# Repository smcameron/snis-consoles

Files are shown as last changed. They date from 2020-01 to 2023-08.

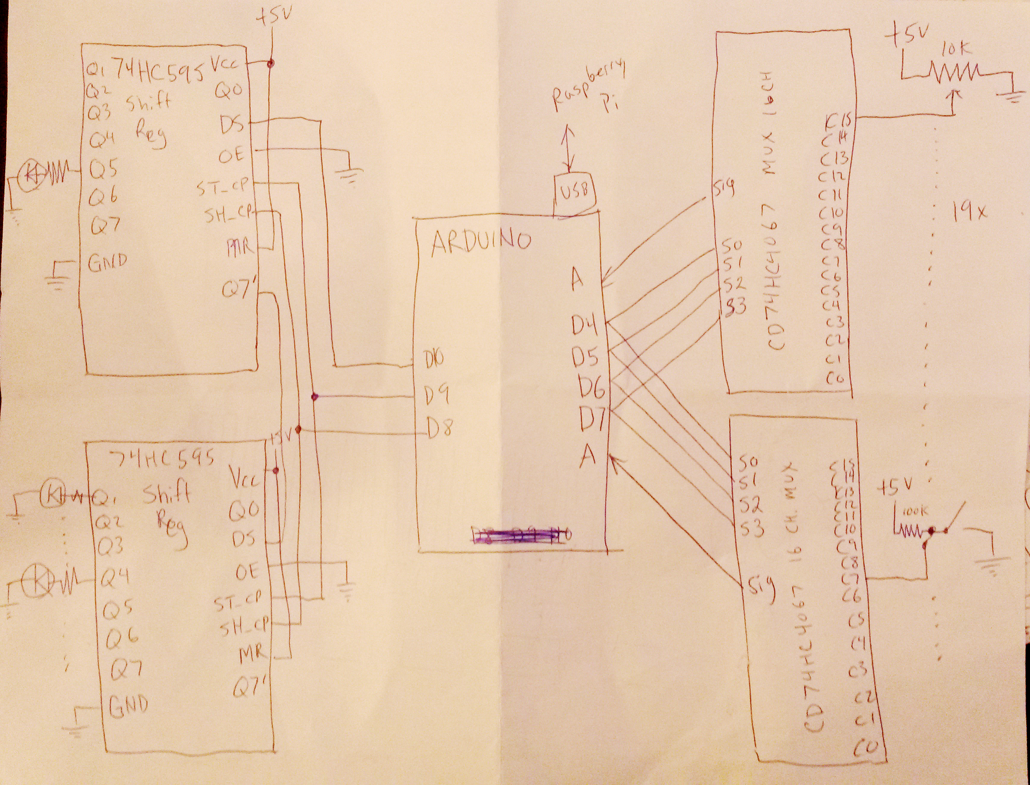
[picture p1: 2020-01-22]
notes/snis-console-circuit-sketch-2020-01-22.jpg

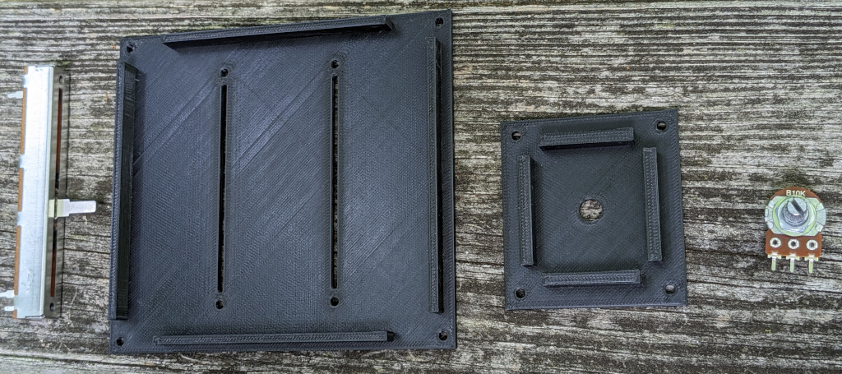
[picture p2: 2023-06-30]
notes/prototype-panel-inserts-back.jpg

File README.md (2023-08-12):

# snis-consoles

This repository contains some code and OpenSCAD designs for physical
consoles for the game <a href="https://spacenerdsinspace.com">Space Nerds in Space</a>.

It is still very much a work in progress.

The basic idea is to run snis_client on a Raspberry Pi 4B for some stations
(Navigation, Engineering, Science, Comms) and build a custom console for each
of these stations with buttons, toggle switches, potentiometer, faders, gauges,
etc.  An arduino (or maybe a Raspberry Pi pico) will marshal all these inputs
and control LEDs and so on, and be connected via USB to the Raspberry Pi 4B
running snis_client.

There are OpenSCAD designs for some 3D printable large illuminated push buttons
built around inexpensive tactile switches, some 3d printable panels to hold these
buttons and allow mounting into a "dashboard", some 3d printable panels for mounting
potentiometers and faders which can then mounted in a dashboard.

NOTE: for the gears and rack and pinion in the flight yoke model, you will
need to clone two additional repositories alongside this repository:

* git@github.com:smcameron/Rack-Pinion-openscadLib.git
* git@github.com:smcameron/meshing-gears-OpenSCAD.git

Here are some notes on my progress so far:

* [Notes](https://spacenerdsinspace.com/snis-consoles/notes.html)

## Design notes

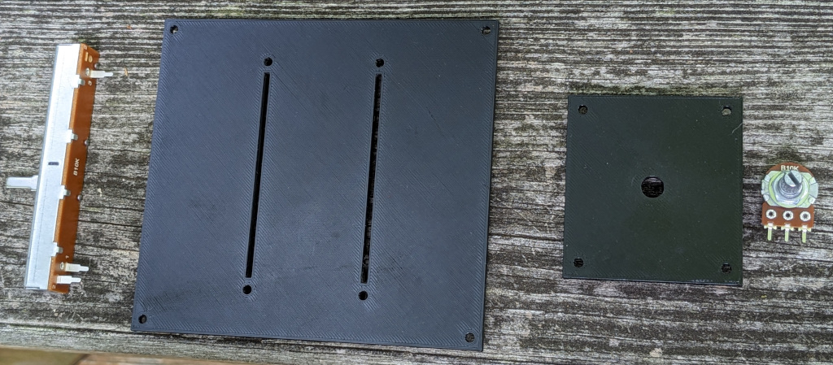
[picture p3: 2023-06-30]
notes/prototype-panel-inserts-front.jpg

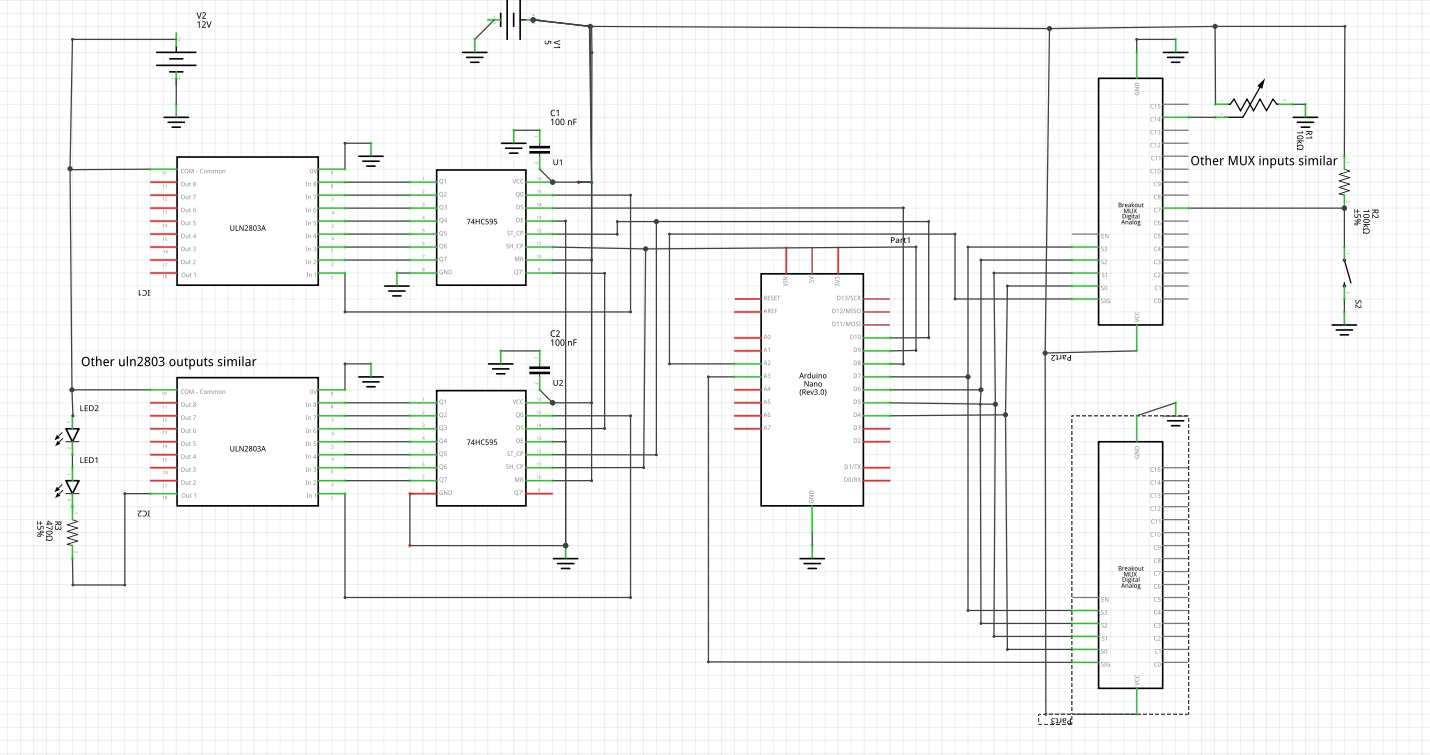
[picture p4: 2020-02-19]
notes/snis-console-circuit.png

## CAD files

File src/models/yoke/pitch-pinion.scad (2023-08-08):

/* using library from : git@github.com:smcameron/Rack-Pinion-openscadLib.git */

include <../../../../Rack-Pinion-openscadLib/RackPinionLibRedesign.scad>

// module pinion (cp, N, width, shaft_diameter, backlash=0){
// cp= circular pitch - for pinion pitch in mm/per as measured along the ptich radius (~1/2 way up tooth)
// N= number of teeth
// width= width of the gear
// shaft_diameter= diameter of hole for shaft
// backlash - I think this is just a bodge for making things fit when printed but I never tested it


/* 
 * 3mm per tooth
 * 65 teeth, = 147*4/3 mm rack length
 * 10mm wide
 * 5mm backing material
 *
 */
pinion(3, 65, 10, 6.0);

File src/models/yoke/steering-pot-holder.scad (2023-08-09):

pot_base_radius = (0.5 * 16.5);
pot_base_depth = 6;
pot_shaft_hole_radius = 3.7;

interior_width = 59;
exterior_width = 75;
plate_thickness = 3.0;

tolerance = 0.75;

$fn = 100;

module pot_tab_hole()
{
	translate(v = [13, 30, -3])
		translate(v = [0, 8.5, 0])
			cylinder(r1 = 1.8, r2 = 1.8, h = 10);
}

module base_plate()
{
	union() {
		translate(v = [-5, 0, 0])
			cube(size = [plate_thickness, interior_width - tolerance, 30]);
		translate(v = [plate_thickness, -8, 0])
			cube(size = [plate_thickness, 15, 30]);
		translate(v = [plate_thickness, interior_width - 8, 0])
			cube(size = [plate_thickness, 15, 30]);
		translate(v = [-2, 0, 0])
			cube(size = [8, 8, 30]);
		translate(v = [-2, 50.2, 0])
			cube(size = [8, 8, 30]);
	}
}

module pot_plate()
{
	difference() {
		translate(v = [-5, 15, 0])
			cube(size = [25, 30, 4]);
		translate(v = [13, 30, -2])
			cylinder(r1 = pot_shaft_hole_radius, r2 = pot_shaft_hole_radius, h = 20);
		pot_tab_hole();
		translate(v = [-5.1, 0, -0.1])
			cube(size = [plate_thickness + 0.1, 100, 2 * plate_thickness]);
	}
}

module gusset()
{
	scale(v = [1, 1, 2]) {
	rotate(v = [0, 0, 1], a = 90)
	difference() {
		cube(size = [4, 10, 10]);
		translate(v = [-0.5, 0, 0])
			rotate(v = [1, 0, 0], a = 45)
				cube(size = [5, 20, 20]);
	}
	}
}

module gussets()
{
	translate(v = [8, 15, 4])
			gusset();
	translate(v = [8, 41, 4])
			gusset();
}

module screw_hole()
{
	rotate(v = [0, 1, 0], a = 90)
		cylinder(r1 = 1.75, r2 = 1.75, h = 100);
}

union() {
union() {
	base_plate();
}

translate(v = [0, -1, 0]) {
	pot_plate();
	gussets();
	translate(v = [-5 + plate_thickness, 5, 0])
		cube(size = [plate_thickness, 15, 30]);
	translate(v = [-5 + plate_thickness, 40, 0])
		cube(size = [plate_thickness, 15, 30]);
}
}

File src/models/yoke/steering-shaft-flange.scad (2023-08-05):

shaft_radius = (0.5 * 22.5);
flange_length = 15;
flange_lip_height = 4;
large_radius = shaft_radius * 1.5;
small_radius = shaft_radius * 1.2;
$fn = 100;

difference() {
	union() {
		translate(v = [0, 0, 0.5 * flange_length]) {
			cylinder(h = flange_length, r1 = small_radius, r2 = small_radius, center = true);
		}
		translate(v = [0, 0, 0.5 * flange_lip_height])
			cylinder(h = flange_lip_height, r1 = large_radius, r2 = large_radius, center = true);
	}
	translate(v = [0, 0, 0.5 * flange_length])
		cylinder(h = flange_length * 2, r1 = shaft_radius, r2 = shaft_radius, center = true);
	translate(v = [-20, 0, 10])
		rotate(v = [0, 1, 0], a = 90)
			cylinder(h = 40, r1 = 2, r2 = 2);
}

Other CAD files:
src/models/yoke/steering-shaft-gear.scad
src/models/cantilever-snap.scad
src/models/case_siding.scad
src/models/face-plate.scad
src/models/fader-60mm-holes.scad
src/models/fader-insert-60mm-array.scad
src/models/gauge/gauge.scad
src/models/gauge/needle.scad
src/models/large-switch-array-holder.scad
src/models/large-switch.scad
src/models/lasercut-lenses.scad
src/models/lower-panel.scad
src/models/nav-2x2-large-switch-array-holder.scad
src/models/nav-2x2-switch-retaining-gasket.scad
src/models/nav-2x5-large-switch-array-holder.scad
src/models/nav-2x5-switch-retaining-gasket.scad
src/models/nav-5x1-large-switch-array-holder.scad
src/models/nav-5x1-switch-retaining-gasket.scad
src/models/nav-5x1-toggle-switch-insert.scad
src/models/nav-5x4-large-switch-array-holder.scad
src/models/nav-impulse-warp-fader-insert.scad
src/models/nav-zoom-pot-insert.scad
src/models/potentiometer-hole.scad
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

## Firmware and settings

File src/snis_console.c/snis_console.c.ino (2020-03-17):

/*
	Copyright (C) 2020 Stephen M. Cameron
	Author: Stephen M. Cameron

	This file is part of Spacenerds In Space.

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
	You should have received a copy of the GNU General Public License
	along with Spacenerds in Space; if not, write to the Free Software
	Foundation, Inc., 51 Franklin St, Fifth Floor, Boston, MA  02110-1301  USA
*/

/* Multiplexer selector pins */
static const int mux_select[4] = { 4, 5, 6, 7 };
static const int mux_input[2] = { A2, A3 };

/* Shift register control pins */
static const int sr_data = 8;
static const int sr_clock = 9;
static const int sr_latch = 10;

/* Changes below +/- 3 won't register... cuts down on spurious triggers
 * Might be able to tighten this up when no longer using the breadboard
 * when the real circuit is built. */
#define MUX_SIGNAL_THRESHOLD 3

static int current_input[32] = { 0 };
static int old_input[32] = { 0 };
static int indicator_led[16] = { 0 };



#define ENGINEERING 1

#ifdef ENGINEERING
#define CONSOLE_CHAR 'E'
#endif
#ifdef WEAPONS
#define CONSOLE_CHAR 'W'
#endif
#ifdef NAVIGATION
#define CONSOLE_CHAR 'N'
#endif
#ifdef COMMS
#define CONSOLE_CHAR 'C'
#endif
#ifdef SCIENCE
#define CONSOLE_CHAR 'S'
#endif
#ifdef DEMON
#define CONSOLE_CHAR 'D'
#endif

void setup()
{
	int i;

	Serial.begin(9600);

	/* Set up output pins for mux channel selection */
	for (i = 0; i < 4; i++)
		pinMode(mux_select[i], OUTPUT);
	pinMode(mux_input[0], INPUT);
	pinMode(mux_input[1], INPUT);
	pinMode(sr_data, OUTPUT);
	pinMode(sr_clock, OUTPUT);
	pinMode(sr_latch, OUTPUT);
	digitalWrite(sr_data, LOW);
	digitalWrite(sr_latch, LOW);
	digitalWrite(sr_clock, LOW);
}

void select_mux_channel(int channel)
{
	for (int i = 0; i < 4; i++)
		digitalWrite(mux_select[i], (channel >> i) & 0x01);
}

void read_mux_input(int current_input[])
{
	for (int i = 0; i < 16; i++) {
		select_mux_channel(i);
		current_input[i] = analogRead(mux_input[0]);
		current_input[i + 16] = analogRead(mux_input[1]);
	}
}

#ifndef TEST_SNIS_CONSOLE
#define printchar print
#define printint print
#define printintln println
#endif

void transmit_input(int datum, int value)
{
	Serial.printchar(CONSOLE_CHAR);
	Serial.printint(datum);
	Serial.printchar('=');
	Serial.printintln(value);
}

void transmit_changed_input(int current_input[], int old_input[])
{
	int i;

	for (i = 0; i < 32; i++) {
		if (abs(current_input[i] - old_input[i]) > MUX_SIGNAL_THRESHOLD) {
			transmit_input(i, current_input[i]);
			old_input[i] = current_input[i];
		}
	}
}

struct serial_input_data {
	int active_command;
#define NO_COMMAND 0
#define LED_STATUS_COMMAND 'L'
	int index;
	int hex_digit_count;
	uint8_t led_values[2];
	uint8_t *value_ptr;
} sid = { 0 };

void update_indicator_leds(void)
{
	int i;

	for (i = 0; i < 16; i++) { /* Shift out 16 bits of LED indicator data to turn on/off 16 indicator LEDs */
		digitalWrite(sr_clock, LOW);
		digitalWrite(sr_data, indicator_led[i] ? HIGH : LOW);
		digitalWrite(sr_clock, HIGH);
	}
	digitalWrite(sr_latch, HIGH); /* Latch the data so it appears on the outputs of the shift registers */
	digitalWrite(sr_latch, LOW);
}

void read_indicator_data_from_snis_client_and_update_leds(void)
{
	/* Sat Feb 22 15:15:14 EST 2020 -- this function is completely untested. */

	int i, inchar, value;
	uint16_t v;

	if (Serial.available() <= 0)
		return;

	/* Read a character... */
	inchar = Serial.read();
	if (inchar == -1) /* no data */
		return;

	switch (inchar) {
	/* LED status values, expect 2 more bytes to indicate status of 16 LEDs */
	case LED_STATUS_COMMAND:
		sid.value_ptr = &sid.led_values[0];
		sid.hex_digit_count = 4; /* 2 bytes with 2 hex digits each */
		sid.active_command = LED_STATUS_COMMAND;
		return;
	default:
		/* If no active command, or we already have the data for the active command
		 * ignore this character and continue.
		 */
		if (sid.active_command == 0 || sid.hex_digit_count <= 0)
			return;

		/* Convert value to integer */
		if (inchar >= '0' && inchar <= '9')
			value = inchar - '0';
		else if (inchar >= 'A' && inchar <= 'F')
			value = inchar - 'A' + 10;
		else
			value = -1;

		/* If we did not get a good value, ignore it. */
		if (value < 0)
			return;
		/* We got a good value, store it */
		if ((sid.hex_digit_count % 2) == 0)
			*sid.value_ptr = ((uint8_t) value << 4) & 0xf0; /* high nybble */
		else
			*sid.value_ptr |= (uint8_t) (value & 0x0f); /* low nybble */
		if (sid.hex_digit_count % 2)
			sid.value_ptr++;
		sid.hex_digit_count--;
		if (sid.hex_digit_count == 0)
			update_indicator_leds();
		break;
	}

	/* If we have still more data to read continue reading more.  */
	if (sid.hex_digit_count != 0)
		return;

	/* We have all the data for the active command, so process it. */
	switch (sid.active_command) {
	case LED_STATUS_COMMAND: /* Update the indicator LED status values with the data */
		sid.active_command = NO_COMMAND;
		memcpy(&v, sid.led_values, sizeof(v));
		for (i = 0; i < 16; i++)
			indicator_led[i] = v & (0x1 << i);
		return;
	default:
		/* Unknown command... */
		return;
	}
}

void loop() {

	read_mux_input(current_input);
	transmit_changed_input(current_input, old_input);
	read_indicator_data_from_snis_client_and_update_leds();
}

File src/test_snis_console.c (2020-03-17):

#include <stdio.h>
#include <stdlib.h>
#include <stdint.h>
#include <string.h>

#define A2 0
#define A3 1

#define INPUT 0
#define OUTPUT 1
#define HIGH 1
#define LOW 0

int analog_values[] = {
	0, 1, 2, 3, 4, 5, 6, 7, 8, 9, 10, 11, 12, 13, 14, 15, 16, 17, 18, 19, 20, 21, 22, 23, 24, 25, 26, 27, 28, 29, 30, 31,
};


int emu_mux_select_pin[] = { 4, 5, 6, 7, };
int emu_mux_select = 0;
int emu_mux_input[] = { A2, A3 };

/* Shift register control pins */
static const int emu_sr_data = 8;
static const int emu_sr_clock = 9;
static const int emu_sr_latch = 10;
static int sr_data_value = 0;
static int sr_clock_value = 0;
static int sr_latch_value = 0;
uint16_t shift_register = 0;
uint16_t shift_register_output = 0;

typedef void (*intfunc)(int x);
typedef int (*intvoidfunc)(void);

static int analogRead(int pin)
{
	printf("Analog read %d\n", pin);

	if (pin == emu_mux_input[0]) {
		printf("Reading mux input 0, emu_mux_select = %d, returning %d\n",
				emu_mux_select, analog_values[emu_mux_select]);
		return analog_values[emu_mux_select];
	} else if (pin == emu_mux_input[1]) {
		printf("Reading mux input 1, emu_mux_select = %d, returning %d\n",
				emu_mux_select, analog_values[emu_mux_select + 16]);
		return analog_values[emu_mux_select + 16];
	}  
	return 0;
}

static void digitalWrite(int pin, int value)
{
	int i;

	printf("digital write pin/value: %d/%d\n", pin, value);

	for (i = 0; i < 4; i++) {
		if (pin == emu_mux_select_pin[i]) {
			emu_mux_select = ((emu_mux_select & ~(0x01 << i)) | (value << i));
			return;
		}
	}

	if (pin == emu_sr_data) {
		sr_data_value = value & 0x01;
	} else if (pin == emu_sr_clock) {
		if (value == HIGH && sr_clock_value == LOW) {
			shift_register = (shift_register << 1) & 0xfffe;
			shift_register |= (sr_data_value & 0x01);
		}
		sr_clock_value = value;
	} else if (pin == emu_sr_latch) {
		if (value == HIGH && sr_latch_value == LOW) {
			shift_register_output = shift_register;
			printf("Latched shift register value: %04x\n", shift_register_output);
		}
		sr_latch_value = value;
	}
}

static void Serial_Begin(int x)
{
	printf("Serial.Begin(%d);\n", x);
}

static void Serial_printint(int x)
{
	printf("%d", x);
}

static void Serial_printintln(int x)
{
	printf("%d\n", x);
}

static void Serial_printchar(int x)
{
	printf("%c", x);
}

static int Serial_read(void)
{
	static int p = 0;
	const char *led_data = "LBEEF";
	int x;

	x = led_data[p];
	p = (p + 1) % 5;
	return x;
}

static int Serial_available(void)
{
	return 1;
}

static void pinMode(int a, int b)
{
	return;
}

struct serial {
	intfunc begin;
	intfunc printint;
	intfunc printintln;
	intfunc printchar;
	intvoidfunc read;
	intvoidfunc available;
} Serial = {
	Serial_Begin,
	Serial_printint,
	Serial_printintln,
	Serial_printchar,
	Serial_read,
	Serial_available,
};

#define TEST_SNIS_CONSOLE

#include "snis_console.c/snis_console.c.ino"

int main(int argc, char *argv[])
{
	printf("Test code for snis_console...\n");
	setup();
	do {
		loop();
	} while (1);
}

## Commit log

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2020-01-25 Refine change detection of multiplexer inputs and tighten up output
    There seems to be a little cross talk and settling time on the mux signal.
    Quite likely this is due to the breadboard though, once I get the real
    circuit built, might be able to tighten this up.
    [snis_console.c.ino]
2020-01-29 Differentiate between different stations in protocol.
    Previously messages from Arduino to host were of the form:
    #X=y\n
    Replace the '#' with a symbol to indicate which console, e.g.
    E=engineering/damage control
    N=Navigation
    W=Weapons
    C=Comms
    S=Science
    D=Demon
    [snis_console.c.ino]
2020-01-31 Copy current_data[i] to old_data[i] when it changes
    Previously we just memcpy'ed the entrie current_data[]
    to old_data[] whether it changed or not. However, this caused
    a bug that the data could very slowly change bit by bit and accumulate
    a large amount of change without ever registering as having changed. If
    we only copy the data when it changes, then small changes that accumulate
    to large changes will register.
    [snis_console.c.ino]
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2020-02-02 add 3d model for switch holder
    [switch.scad]
2020-02-02 Fix model to be a proper 2-manifold or whatever
    [switch.scad]
2020-02-03 Refine button pusher design
    [switch.scad]
2020-02-03 increase size of cavity to hold tactile switch
    [switch.scad]
2020-02-03 Refine rabbet on button pusher
    [switch.scad]
2020-02-03 Add a flange to the case for mounting in a panel
    [switch.scad]
2020-02-03 Inset the button cavity deeper into the floor of the button holder
    [switch.scad]
2020-02-03 Adjust LED hole position
    [switch.scad]
2020-02-04 Adjust button pusher contact point
    [switch.scad]
2020-02-04 Add friction arms to the button holder
    [switch.scad]
2020-02-06 More little adjustments -- at this point, the pieces fit together and actually work.
    [switch.scad]
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2020-02-19 Remove bypass caps from 4067 breakout board - it already has them built in
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2020-03-17 Fix bug in read_indicator_data_from_snis_client
    It was only reading 2 hex digits but needs to read 4 digits for 2 bytes
    [snis_console.c.ino]
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2021-08-28 Allow gangs of switches
    [switch.scad]
2022-08-17 Add fader60mm-holes.scad
    [fader-60mm-holes.scad]
2022-08-17 Add toggle-switch-hole.scad
    [toggle-switch-hole.scad]
2022-08-17 Add potentiometer-hole.scad
    [potentiometer-hole.scad]
2022-08-17 Add switch-hole.scad
    [switch-hole.scad]
2022-08-17 Add test-panel.scad
    [test-panel.scad]
2023-06-16 Add model for 3d printable 60mm fader array insert
    [fader-insert-60mm-array.scad]
2023-06-19 Add potentiometer-insert.scad
    [potentiometer-insert.scad]
2023-06-28 use differenct to subtract test panel holes from test panel
    [test-panel.scad]
2023-06-28 Make potentiometer-insert.scad include-able
    [potentiometer-insert.scad]
2023-06-28 Add nav-5x1-toggle-switch-insert.scad
    [nav-5x1-toggle-switch-insert.scad]
2023-06-28 Add nav-zoom-pot-insert.scad
    [nav-zoom-pot-insert.scad]
2023-06-28 Add nav-impulse-warp-fader-insert.scad
    and make fader-insert-60mm-array.scad "include-able".
    [fader-insert-60mm-array.scad, nav-impulse-warp-fader-insert.scad]
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2023-06-28 potentiometer-insert.scad: Remove duped parameter assignments
    and remove extraneous echo command
    [potentiometer-insert.scad]
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2023-06-28 Remove duped parameter values
    [nav-5x1-toggle-switch-insert.scad, nav-zoom-pot-insert.scad]
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2023-06-30 Add cantilever-snap.scad
    [cantilever-snap.scad]
2023-06-30 Make fader screw holes optional
    [fader-insert-60mm-array.scad, nav-impulse-warp-fader-insert.scad]
2023-06-30 Replace screw holes with cantilever snap arms for faders
    [cantilever-snap.scad, fader-insert-60mm-array.scad, nav-impulse-warp-fader-insert.scad]
2023-07-01 cantilever-snap: add fader fit tolerance setting
    [cantilever-snap.scad]
2023-07-01 Add test-60mm-fader-snap-fit.scad
    [test-60mm-fader-snap-fit.scad]
2023-07-01 Make number of fader snap arms configurable
    [cantilever-snap.scad, fader-insert-60mm-array.scad, nav-impulse-warp-fader-insert.scad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]
2023-07-01 Replaced screw holes with cantilevered snap arms
    [cantilever-snap.scad, fader-insert-60mm-array.scad]
2023-07-02 Add test-cantilever-snap.scad
    [test-cantilever-snap.scad]
2023-07-02 Improve cantilever snap
    [cantilever-snap.scad, fader-insert-60mm-array.scad, nav-impulse-warp-fader-insert.scad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]
2023-07-02 Add throttle-handle.scad
    [throttle-handle.scad]
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2023-07-03 Enlarge hole for fader tang
    [throttle-handle.scad]
2023-07-03 Make throttle handle longer
    [throttle-handle.scad]
2023-07-03 Factor out face-plate.scad
    [face-plate.scad, fader-insert-60mm-array.scad]
2023-07-03 fix faceplate
    [face-plate.scad, fader-insert-60mm-array.scad]
2023-07-03 Improve potentiometer insert
    [potentiometer-insert.scad]
2023-07-06 Add large-switch.scad
    [large-switch.scad]
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2023-07-07 Add large switch array holder
    [large-switch-array-holder.scad]
2023-07-08 Generalize large switch array holder
    [large-switch-array-holder.scad, nav-5x1-large-switch-array-holder.scad, nav-5x4-large-switch-array-holder.scad]
2023-07-10 Add nav-2x5-button-array
    [nav-2x5-large-switch-array-holder.scad]
2023-07-15 Increase size of potentiometer hole
    [nav-zoom-pot-insert.scad]
2023-07-15 Add case_siding.scad
    [case_siding.scad]
2023-07-15 Add lasercut-lenses.scad
    [lasercut-lenses.scad]
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2023-07-18 notes: Add idea about USB HID device and RGB LED control
    If we have 3 bytes of RGB data, we can individually control up
    to 24 on/off LEDs.
2023-07-18 Add yoke model
    [yoke.scad]
2023-07-20 yoke: set pipe radii and clearances
    [yoke.scad]
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2023-07-28 Update notes: received 200x 4p4c jacks
    Received:
    200x 4p4c jacks
    1x 6p6c coupler
    2x 6p6c cables (should work with my existing rudder pedals)
    1x Rii mini keyboard
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2023-08-03 Add more yoke component models
    [yoke-cage.scad]
2023-08-03 Add switch jack holder model
    [switch-jack-holder.scad]
2023-08-05 Add steering shaft flange model
    [steering-shaft-flange.scad]
2023-08-05 Add steering shaft gear model
    [steering-shaft-gear.scad]
2023-08-08 Add steering shaft mounts
    [steering-shaft-mount.scad]
2023-08-08 Adjust steering shaft mounts
    [steering-shaft-mount.scad]
2023-08-08 Add steering potentiometer holder
    [steering-pot-holder.scad]
2023-08-08 Add pitch rack model
    [pitch-rack.scad]
2023-08-08 Add pitch pinion model
    [pitch-pinion.scad]
2023-08-08 Add pitch pot holder
    [pitch-pot-holder.scad]
2023-08-09 Add yoke handle to steering shaft adapter model
    [yoke-shaft-adapter.scad]
2023-08-09 Double size of roll potentiometer gear
    There wasn't enough clearance to get the small gear to mesh well
    [steering-shaft-gear.scad]
2023-08-09 Adjust roll pot holder for new roll pot gear
    [steering-pot-holder.scad]
2023-08-11 Update links to gear repos
    [steering-shaft-gear.scad]
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2023-08-15 Add switch retaining gasket models
    [large-switch-array-holder.scad, nav-2x2-large-switch-array-holder.scad, nav-2x2-switch-retaining-gasket.scad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]
2023-08-16 large-switch: make large switch 5mm shorter
    Makes it print faster with lest plastic and no loss of
    functionality.
    [large-switch.scad]
2023-08-16 large-switch: make tactile switch terminals more accessible
    Use a truncated cone instead of a cylinder for the space around
    the switch terminals so they aren't quite so tightly surrounded
    by plastic which makes for easier soldering.
    [large-switch.scad]
2023-09-03 Add gauge model
    [gauge.scad]
2023-09-03 Add gauge needle model
    [needle.scad]
2023-09-10 Add steering column shroud model
    [steering-shaft-shroud.scad]
2023-09-17 Remove some snap arms from nav warp/impulse control
    [fader-insert-60mm-array.scad]
2023-09-17 Add screw holes to warp/impulse control panel insert
    [fader-insert-60mm-array.scad, nav-impulse-warp-fader-insert.scad]
2023-10-02 Add model for lower panel
    [lower-panel.scad]
2023-10-02 Add model for upper panel
    [upper-panel.scad]
2023-10-28 Parameterize case siding by lengths and angles
    [case_siding.scad]

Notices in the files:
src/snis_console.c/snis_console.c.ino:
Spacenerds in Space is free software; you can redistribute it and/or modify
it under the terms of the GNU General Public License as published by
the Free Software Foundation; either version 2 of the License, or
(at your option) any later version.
